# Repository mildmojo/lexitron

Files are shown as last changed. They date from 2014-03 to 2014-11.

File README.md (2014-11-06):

lexitron
========

Plans, models, firmware associated with RunJumpDev's arcade cabinet, the [Lexitron](http://runjumpdev.org/lexitron).

## Microcontrollers

At launch, the Lexitron used two Arduino-compatible microcontrollers to drive
the LEX button and sense coin insertions. The LEX button is a SUZO-HAPP
[large green illuminated pushbutton](http://na.suzohapp.com/all_catalogs/pushbuttons/D54-0004-13)
connected to a [Teensy 2.0](http://pjrc.com/store/teensy_pins.html) board that's
programmed to act like a USB keyboard. The coin door switches are wired to an
[Adafruit Trinket](http://www.adafruit.com/products/1501) that's also programmed
to act like a USB keyboard.

We've had some reliability issues with the Trinket. It's emulating USB in
software, and that's pretty taxing for its ATtiny85 chip. Occasionally it
doesn't send a keystroke, sometimes it sends the keystroke several seconds (!!)
late. We're looking at replacing it with a [Pro Trinket](http://www.adafruit.com/products/2000)
(with an ATmega328 chip) or a Digispark Pro (ATtiny167 w/external crystal).
These physically-small boards let us mount the controller on the coin
mechanism itself.

The Teensy continues to be rock-solid. It scoffs at the menial task of reading
a switch and sending keystrokes. It's got a closed-source bootloader, is way
overpowered for the job, and costs much more than you need to pay for this
functionality, but it's still cheap and provides peace of mind.

## Adafruit Trinket in Windows

Setting up the Arduino IDE for the Trinket in Windows was kind of
a bear.

- Download the [Arduino IDE v1.0x](http://arduino.cc/en/Main/Software)
  & install. (Adafruit doesn't yet support v1.5.x)
- Follow Adafruit's ["slow way" instructions](http://learn.adafruit.com/introducing-trinket/setting-up-with-arduino-ide#the-slow-way)
  for setting up the Trinket with the Arduino IDE.
- Download Adafruit's [Windows driver](http://learn.adafruit.com/usbtinyisp/download)
  for the USBtinyISP and unzip it somewhere.
- In Device Manager, right-click the Trinket, update driver, and
  point to the place where you unzipped the Windows driver.
- Grab the [Bounce2](https://github.com/thomasfredericks/Bounce-Arduino-Wiring)
  and [TrinketKeyboard](https://github.com/adafruit/Adafruit-Trinket-USB)
  libraries and put them in folders in 
  C:\Users\<user>\Documents\Arduino\libraries.
- Start the Arduino IDE.
- Make sure Tools => Board is set to "Adafruit Trinket 16MHz".
- Make sure Tools => Programmer is set to "USBtinyISP".
- Verify (compile) the sketch.
- Press the Trinket's reset button.
- While the Trinket is flashing red, hit the Arduino IDE upload button.

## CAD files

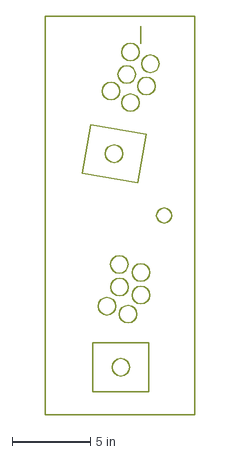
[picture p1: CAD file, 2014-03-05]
plans/control_panel.dxf
9.56 x 25.5 in

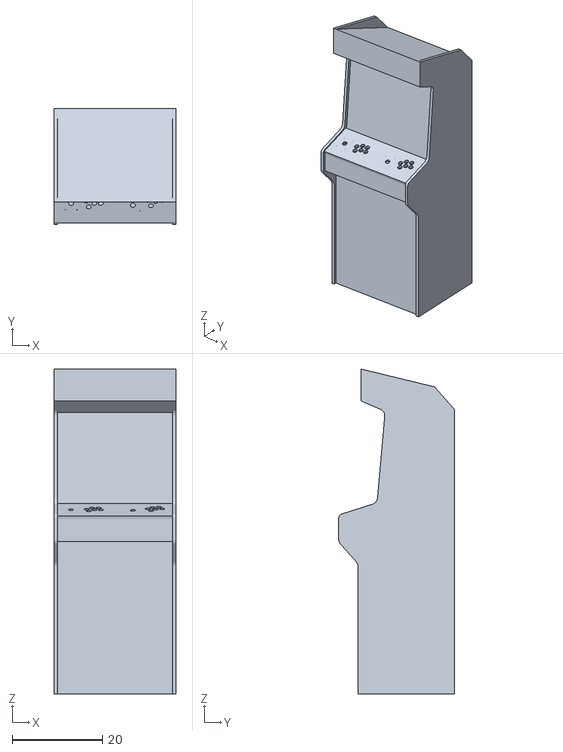
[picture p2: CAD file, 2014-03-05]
plans/lexitron3d.stl
27.0 x 25.6 x 71.9

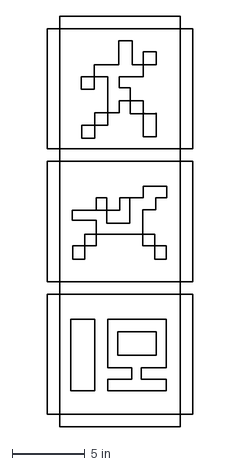
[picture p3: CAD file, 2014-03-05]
plans/run_jump_dev_logo.dxf
10.0 x 28.3 in

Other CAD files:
plans/cab_parts.dxf
plans/kick_plate.dxf
plans/lexitron_sides.dxf
plans/monitor_stand.dxf
plans/lexitron3d.obj

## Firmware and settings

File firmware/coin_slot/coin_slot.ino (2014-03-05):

/*
 * coin_slot.ino
 *
 * One-key USB keyboard using the Adafruit Trinket microcontroller.
 *
 * Designed to report coin insertion events on Run Jump Dev's Lexitron
 * arcade cabinet. Sends a '=' keydown/keyup each time the coin switch
 * is tripped. Wire SWITCH_PIN -> switch -> ground.
 *
 * Part of the Lexitron project:
 *   https://github.com/runjumpdev/lexitron
 *
 * Adafruit Trinket settings:
 *   Board Type: Adafruit Trinket 16MHz
 *   Programmer: USBtinyISP
 *
 * Dependencies:
 *   Bounce2: https://github.com/thomasfredericks/Bounce-Arduino-Wiring
 *   TrinketKeyboard: https://github.com/adafruit/Adafruit-Trinket-USB
 *
 */

#include <Bounce2.h>
#include <TrinketKeyboard.h>

// Magic numbers
#define SWITCH_PIN  0
#define LED_PIN     1
#define DEBOUNCE_MS 10
#define COIN_KEY    KEYCODE_EQUAL // '=' key

// Globals
Bounce coin_switch = Bounce();

void setup() {
  pinMode(SWITCH_PIN, INPUT_PULLUP);
  coin_switch.attach(SWITCH_PIN);
  coin_switch.interval(DEBOUNCE_MS);
  TrinketKeyboard.begin();
}

void loop() {
  TrinketKeyboard.poll();

  if (coin_switch.update()) {
    // Switch pin goes high to low when closed.
    if (coin_switch.read()) {
      key_up();
      led_off();
    } else {
      key_down();
      led_on();
    }
  }
}

void key_down() {
  //TrinketKeyboard.typeChar(COIN_KEY);
  TrinketKeyboard.pressKey(0, COIN_KEY);
}

void key_up() {
  TrinketKeyboard.pressKey(0, 0);
}

void led_on() {
  digitalWrite(LED_PIN, HIGH);
}

void led_off() {
  digitalWrite(LED_PIN, LOW);
}

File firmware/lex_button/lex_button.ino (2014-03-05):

/*
 * lex_key.ino
 *
 * One-key keyboard that sends an additional keystroke if the key is
 * held down too long.
 *
 * Designed to be connected to the LEX button on Run Jump Dev's Lexitron
 * arcade cabinet. Tap to start a game, long press to quit back to the
 * launcher.
 *
 * Teensy 2.0 settings:
 *   USB Type: Keyboard + Mouse + Joystick
 *   CPU Speed: 1MHz
 *   Keyboard Layout: US English
 *   
 */

// Magic numbers
const int ledPin = 11;
const int switchPin = 3;
const int LOOP_DELAY = 50;

// Configuration
const int LONGPRESS_TIME = 2000;
const char SHORT_KEY = '[';
const char LONG_KEY = ']';

// Globals
int short_down = 0;
int short_down_last = 0;
int long_down = 0;
int long_down_last = 0;
int timer = 0;

void setup() {
  pinMode(switchPin, INPUT_PULLUP);
  Keyboard.begin();
}

void loop() {
  if (digitalRead(switchPin) == LOW)
    buttonDown();
  else
    buttonUp();

  // Update history for next loop.
  short_down_last = short_down;
  long_down_last = long_down;
  delay(LOOP_DELAY);
}

void buttonDown() {
  // Debounce button; make sure it's held down for at least LOOP_DELAY.
  short_down = timer >= LOOP_DELAY;
  long_down = timer >= LONGPRESS_TIME;
  
  if (long_down && !long_down_last) {
    ledOn();
    // On long button down, tap long-press key.
    Keyboard.press(LONG_KEY);
  } else {
    // Flash LED when first pressed.
    if (timer == 0) {
      ledOn();
    } else {
      ledOff();
    }
    // On button down, depress short-press key. 
    if (short_down != short_down_last) {
      Keyboard.press(SHORT_KEY);
    }
    // Count time elapsed to see if short press becomes a long press.
    timer += LOOP_DELAY;
  }
}

void buttonUp() {
  // Reset all state, wait for next press.
  short_down = 0;
  long_down = 0;
  timer = 0;
  ledOff();
  // On button up, release short-press key.
  if (short_down != short_down_last) {
    Keyboard.release(SHORT_KEY);
  }
  if (long_down != long_down_last) {
    Keyboard.release(LONG_KEY);
  }
}

void ledOn() {
  digitalWrite(ledPin, HIGH);
}

void ledOff() {
  digitalWrite(ledPin, LOW);
}

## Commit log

2014-03-05 Adds LEX button and coin slot microcontroller firmware.
2014-03-05 Adds 3D models, CNC layouts, assembly plans.
    [cab_parts.dxf, control_panel.dxf, kick_plate.dxf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]
2014-03-05 Refactors coin_slot.ino. Windows instructions:
    Setting up the Arduino IDE for the Trinket in Windows was kind of
    hellish.
    - Download the Arduino IDE v1.05 & install.
    - Follow Adafruit's "slow way" instructions for setting up the
    Trinket with the Arduino IDE.
    (http://learn.adafruit.com/introducing-trinket/setting-up-with-arduino-ide#the-slow-way)
    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
2014-03-07 Updates assembly diagram with more dimensions.
